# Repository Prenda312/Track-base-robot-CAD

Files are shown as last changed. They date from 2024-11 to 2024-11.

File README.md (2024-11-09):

To view the final assembly, please open assembly V3.SLDASM. This CAD model represents a track-based colon endoscopic robot equipped with depth perception stereo cameras. Due to the colon's limited space, the robot’s design prioritizes a simple and efficient drive mechanism.

The TSER (Track-based Stereo Endoscopic Robot) uses a worm gear drive, widely adopted in endoscopic robots for its 90° power transmission, allowing motors to align with the robot’s body and minimize overall size. This mechanism also enables a single worm gear to drive multiple wheels, increasing contact with the colon wall while reducing drive failure risks.

Inspired by prior designs, our TSER optimizes size and reliability by relocating tracks to the corners of the robot, maximizing contact with the colon wall and maintaining movement consistency even in challenging orientations. The robot’s symmetrical design allows it to maintain traction and remain operational, even after flipping, through carefully angled tracks that enhance mobility without increasing size.

The TSER structure features rectilinear movement and two degrees of freedom driven by two motors, each with a reduction ratio of 136. The drive force is efficiently transferred to timing pulleys, ensuring compact dimensions. To manage axial forces from the worm gear, a thrust ball bearing supports stability and protects the motor.

To avoid damage to colonic tissue, the PDMS track is biocompatible, with micro-patterned surfaces to increase friction. All prototype parts were manufactured using 3D printing: the shell was created using SLA technology, while precise drive components were fabricated with multi-jet printing

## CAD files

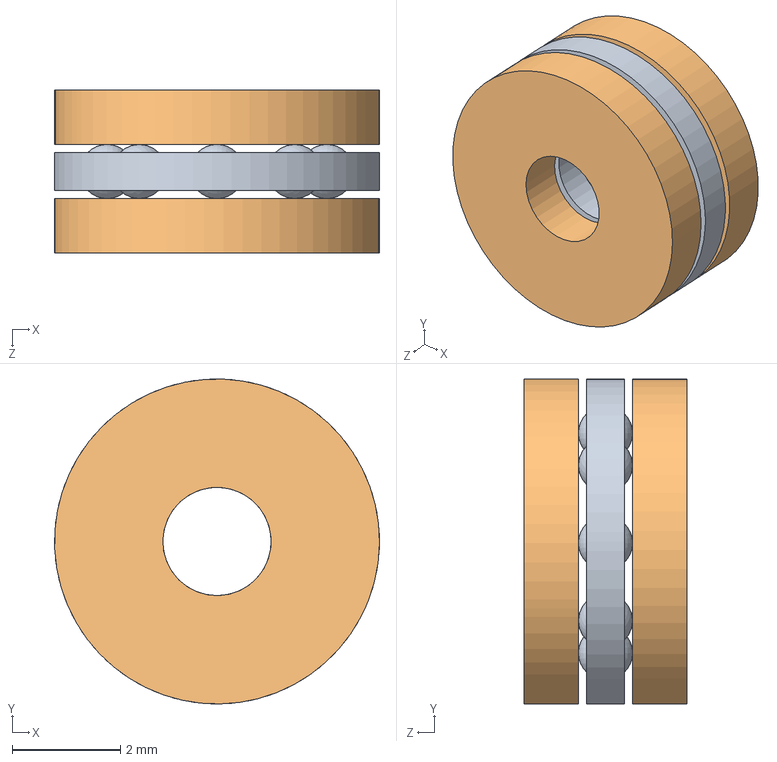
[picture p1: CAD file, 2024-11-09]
推力球轴承/推力球轴承.SLDASM
6.00 x 6.00 x 3.00 mm
推力球轴承
推力球轴承_2 x 2

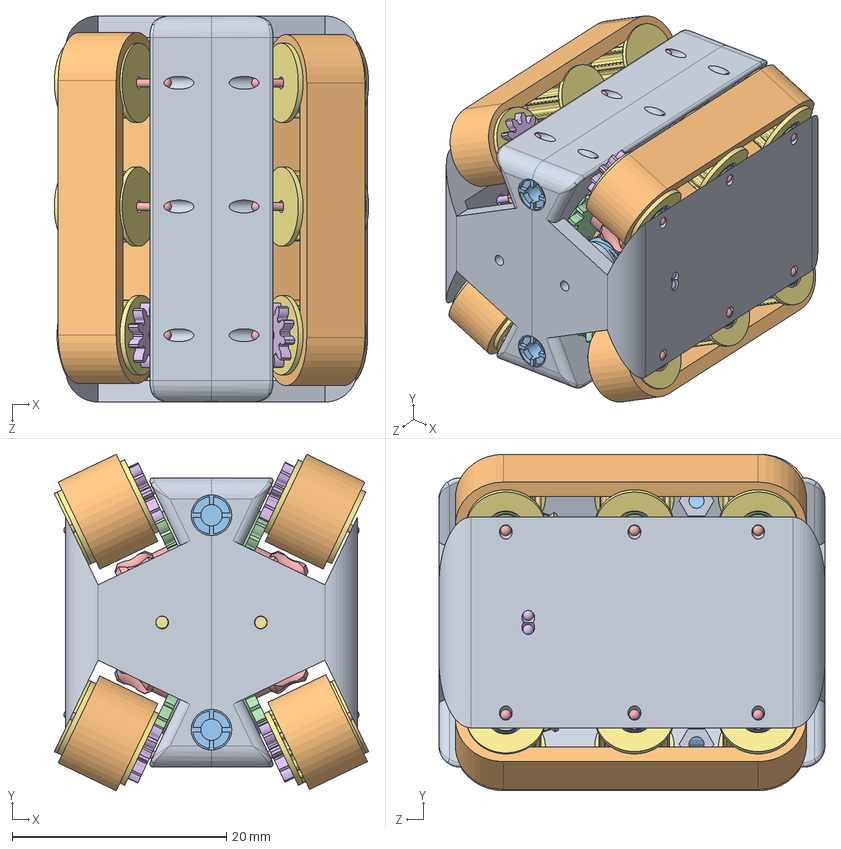
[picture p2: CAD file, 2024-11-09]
assembly v3.SLDASM
29.3 x 31.4 x 36.0 mm
shell v3 x 2
240-motor x 2
右旋蜗杆2×0.5-single x 2
spur gear-20×0.5 x 4
右旋蜗轮7×0.5-single x 4
spur gear-10×0.5 x 4
pulley gear x 12
推力球轴承 x 2
推力球轴承_2 x 4
Tread x 4
CMOS x 2
3mm bearing x 12
8mm 轴 x 12
8mm 轴_2 x 4
电机轴 x 2

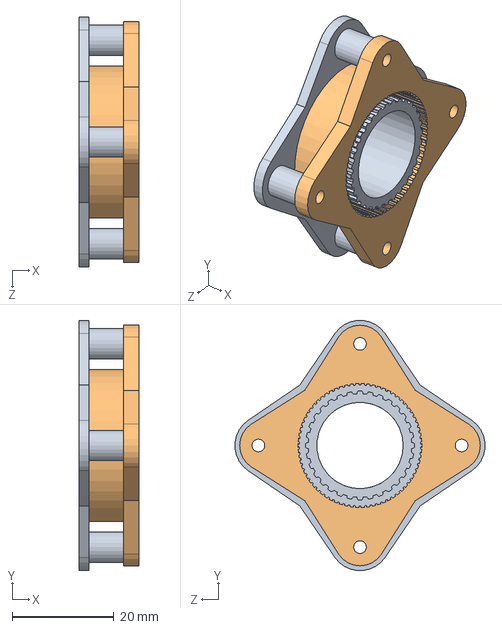
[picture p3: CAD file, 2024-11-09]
tread template final v2.SLDASM
11.8 x 49.2 x 49.2 mm
tread template part2
tread template part1

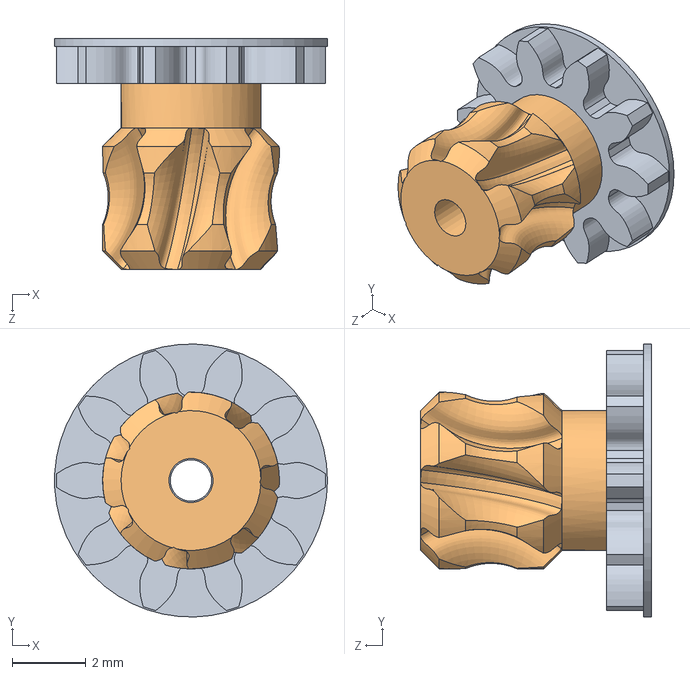
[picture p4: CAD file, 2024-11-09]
spur-worm gear.SLDASM
7.40 x 7.40 x 6.26 mm
spur
右旋蜗轮7×0.5-single

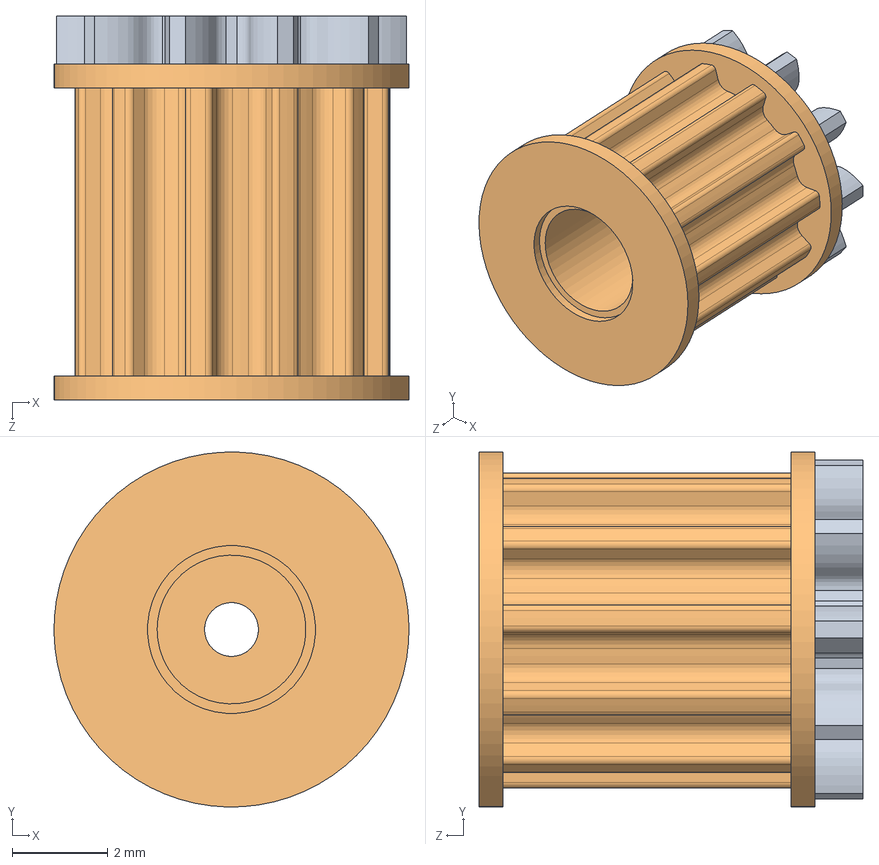
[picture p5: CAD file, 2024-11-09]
spur-pulley gear.SLDASM
7.40 x 7.40 x 8.00 mm
spur mesh
pulley gear

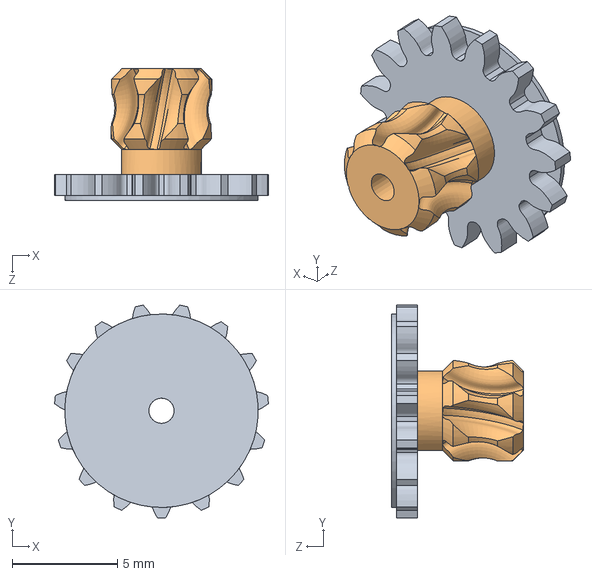
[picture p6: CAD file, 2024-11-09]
spur worm-15_0.6.SLDASM
10.2 x 10.1 x 6.26 mm
spur gear-15×0.6
右旋蜗轮7×0.5-single

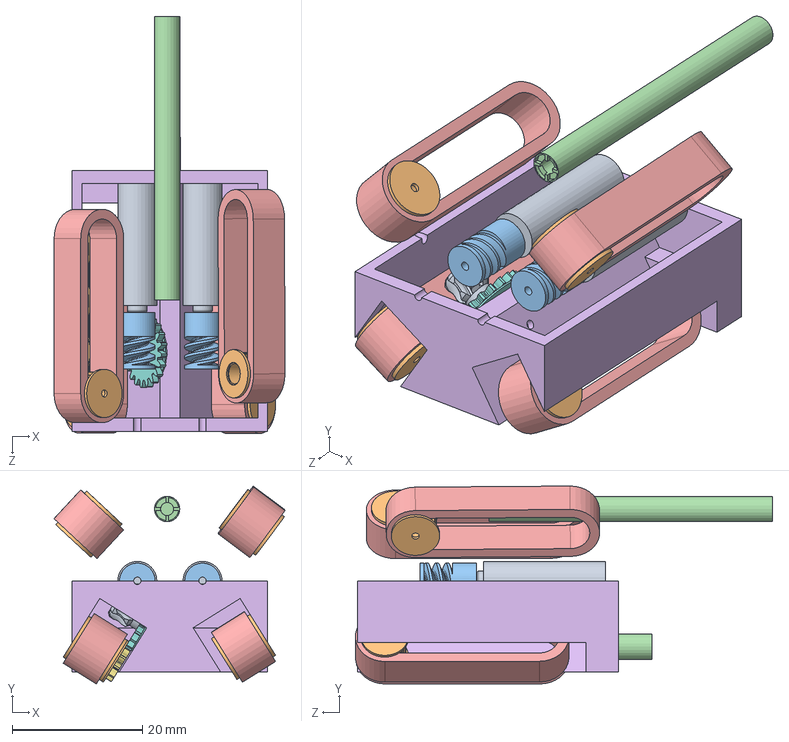
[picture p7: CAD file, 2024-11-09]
assembly.SLDASM
35.4 x 30.4 x 64.0 mm
240-motor x 2
pulley gear x 7
右旋蜗杆2×0.5-single x 2
camera x 2
Tread x 4
spur gear-10×0.5
spur gear-20×0.5
右旋蜗轮7×0.5-single

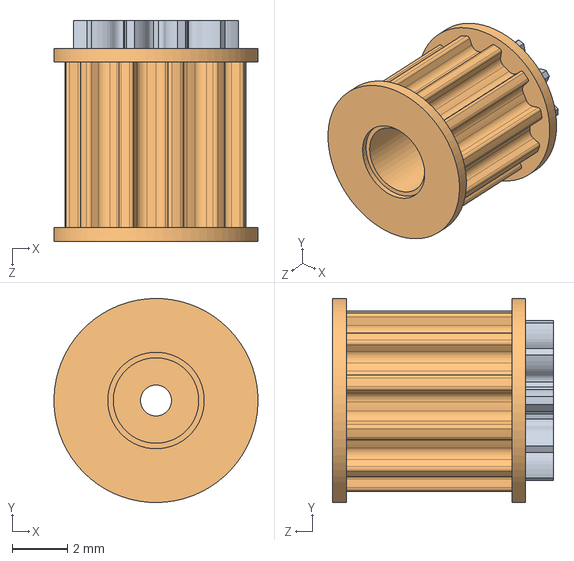
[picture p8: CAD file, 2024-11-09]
spur pulley-10_0.5.SLDASM
7.40 x 7.40 x 8.00 mm
spur gear-10×0.5
pulley gear

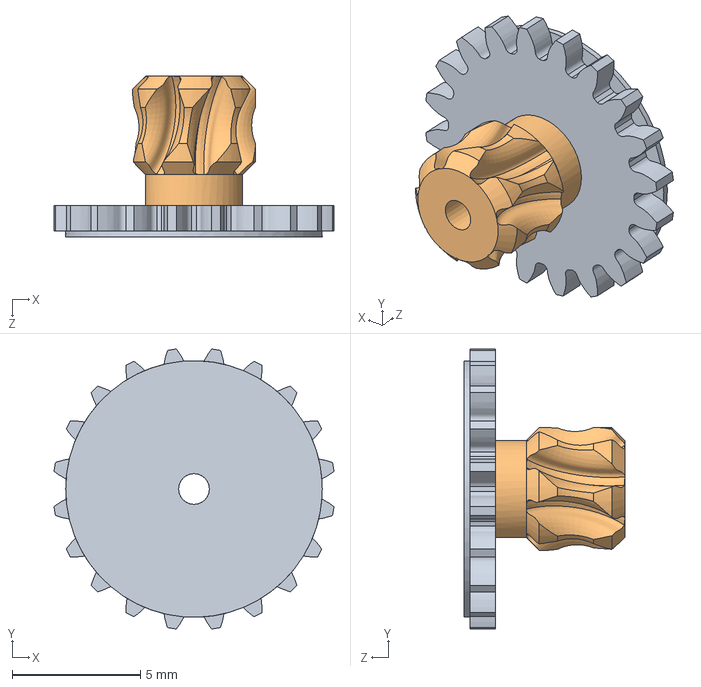
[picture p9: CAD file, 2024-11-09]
spur worm-20_0.5.SLDASM
10.9 x 10.9 x 6.26 mm
spur gear-20×0.5
右旋蜗轮7×0.5-single

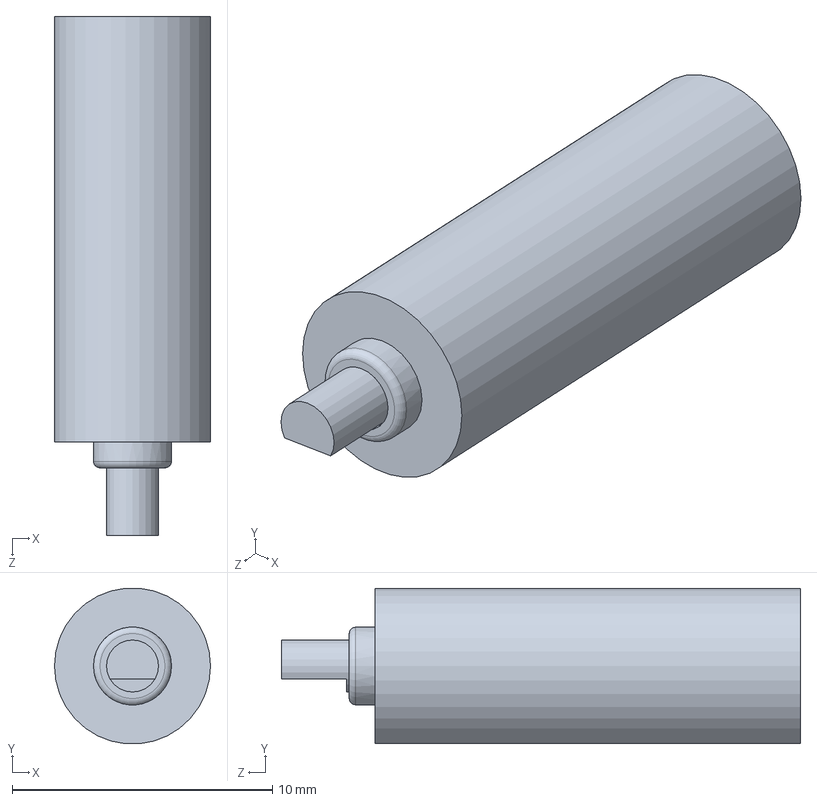
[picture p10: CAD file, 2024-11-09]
motor/1200-motor.SLDPRT
6.00 x 5.97 x 19.9 mm

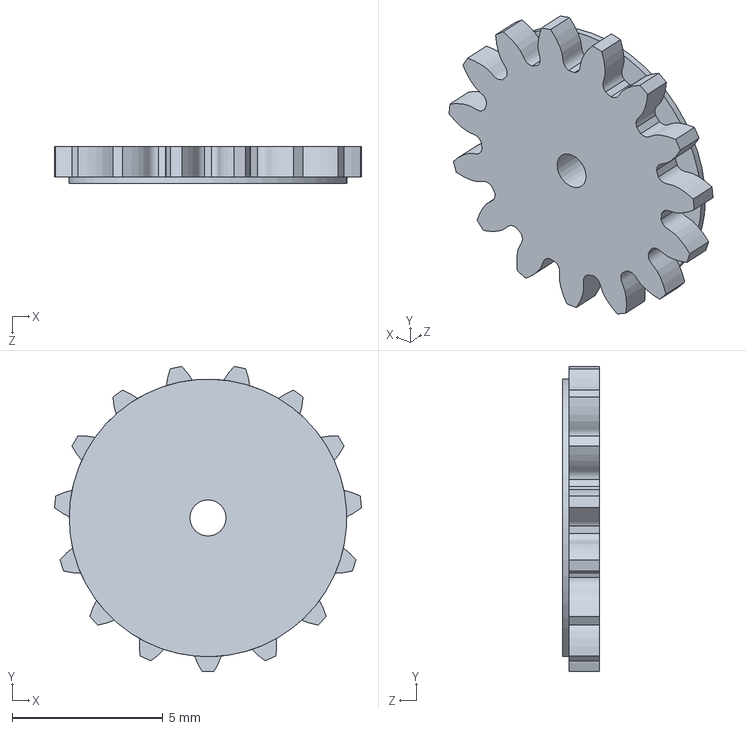
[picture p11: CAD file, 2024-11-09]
spur gear-15×0.6.SLDPRT
10.2 x 10.1 x 1.22 mm

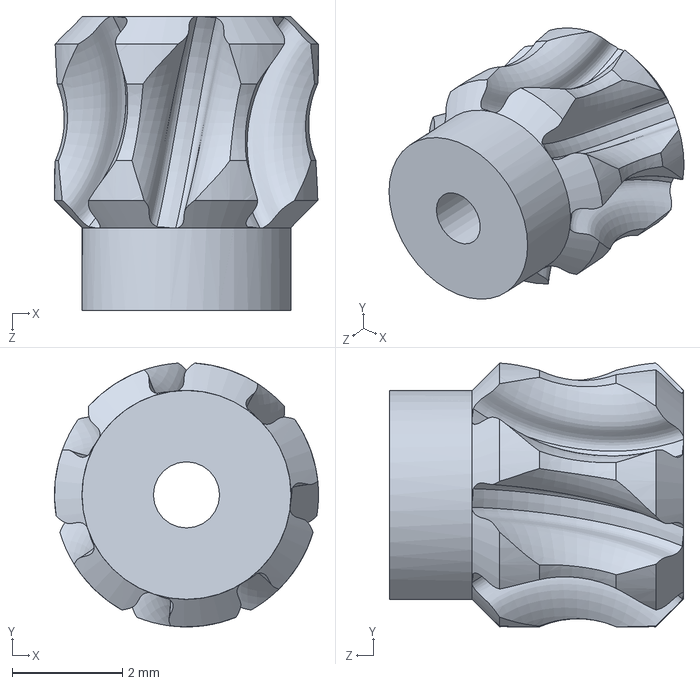
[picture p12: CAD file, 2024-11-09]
worm/右旋蜗轮7×0.5-single.SLDPRT
4.79 x 4.79 x 5.34 mm

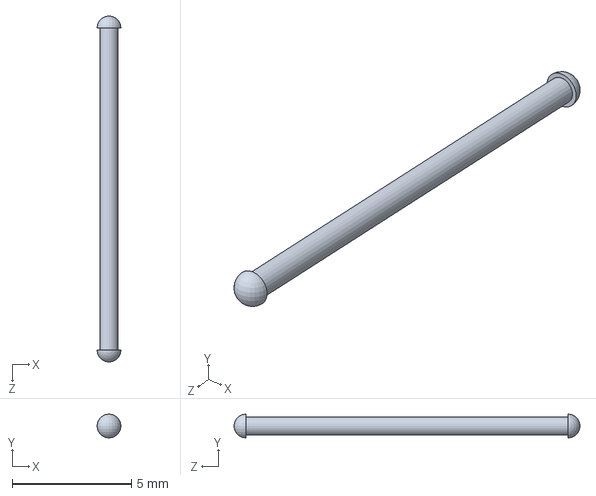
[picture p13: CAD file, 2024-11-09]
轴/8mm 轴_2.SLDPRT
1.00 x 1.00 x 14.5 mm

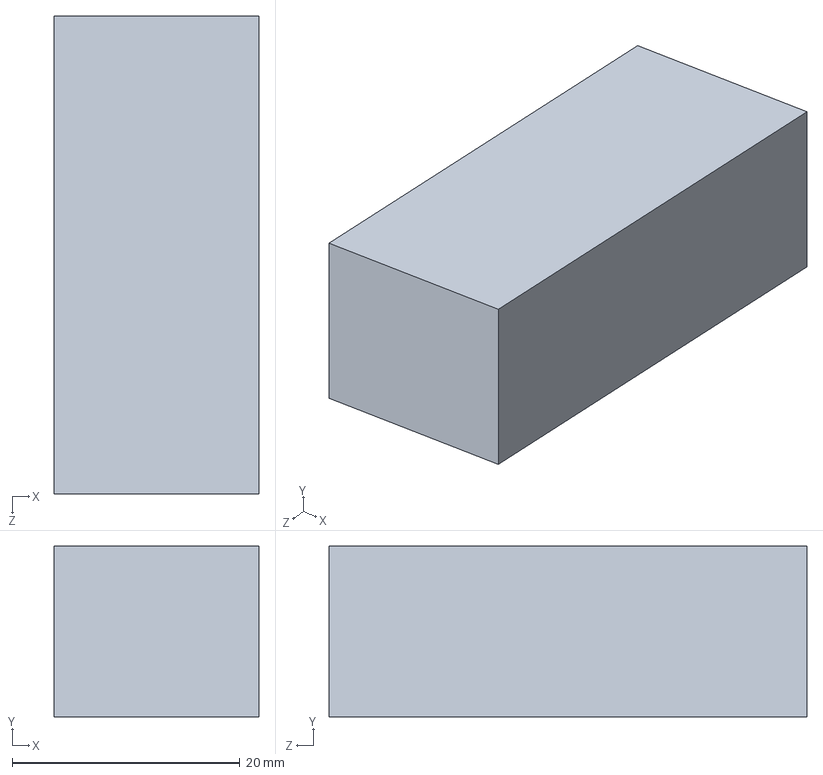
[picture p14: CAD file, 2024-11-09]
cubic.SLDPRT
18.0 x 15.0 x 42.0 mm

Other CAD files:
spur pulley-10_0.6.SLDASM
motor/motor.SLDPRT
worm/右旋蜗杆2×0.5-single.SLDPRT
推力球轴承/推力球轴承_2.SLDPRT
3mm bearing.SLDPRT
CMOS.SLDPRT
Tread.SLDPRT
assembly v2.SLDASM
cam holder.SLDPRT
camera.SLDPRT
motor/240-motor.SLDPRT
pulley gear.SLDPRT
screw.SLDASM
shell v2.SLDPRT
shell v2.STL
shell v3.SLDPRT
shell.SLDPRT
spur gear-10×0.5.SLDPRT
spur gear-10×0.6.SLDPRT
spur gear-20×0.5.SLDPRT
spur mesh.SLDPRT
spur.SLDPRT
timing belt case.SLDPRT
tread template final v.STL
tread template final v.sldprt
tread template final.STL
tread template final.sldprt
tread template part1 v2.STL
tread template part1.STEP
tread template part1.STL
tread template part1.sldprt
tread template part2 v2.STL
tread template part2.STEP
tread template part2.STL
tread template part2.sldprt
tread template.sldprt
同步带.SLDPRT
同步带template.SLDPRT
弧齿锥齿轮14×1-100deg-screw.SLDPRT
弧齿锥齿轮14×1-100deg.SLDPRT
推力球轴承/推力球轴承.SLDPRT
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
